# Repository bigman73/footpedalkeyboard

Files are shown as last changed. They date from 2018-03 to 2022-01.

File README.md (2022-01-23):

# Foot Pedal Keyboard
A foot pedal keyboard, using Korg EC5, Arduino and Python
Converts pedal button events into operating system virtual keyboard sequences.

## Sample applications

### Media editing 📸
Control media editing software, such as Adobe Photosop and Premiere, with your foot

### Program code 👨‍💻
Use the foot keyboard pedal to send macros to a code IDE, such as Visual Studio Code

### Practicing musical instruments 🎸
Control playback with your foot, without stopping the practice. The hands stay on the instrument (e.g, Bass guitar) and hitting a foot pedal rewinds the playback to the start.

### Using with Practice#
For example: If Pedal A is clicked (pressed and released) then the python driver will generate a Media Prev keyboard stroke on the operating system. A musician can then control music playback by using his/her feet, a very natural way for musicians that use foot pedals for effects and volume control, when playing instruments such as guitar, bass guitar and keyboards.

Originally, I wanted to be able to able to control [Practice#](https://github.com/bigman73/practicesharp), my open source practice application, with my feet - instead of getting out of practice position and having to use my hands in order control the application 
With Practice# the setup is as followes:
+ Pedal A -> Look back (key = l)
+ Pedal B -> Rewind a few seconds back (key = ,)
+ Pedal C -> Toggle Play / Pause (key = space)
+ Pedal D -> Slow down (key = s)
+ Pedal E -> Speed up (key = f)

But I decided to make a more generic solution. The python driver supoorts dynamic supports any desktop application through an easy to configure json file (key-mappings.json). The default configuration file contains Chrome mappings - a tab can be closed with Pedal E!  

### Video games
A foot keyboard can provide extra keys to use in games such as first person shooters (FPS).
For example: Pedal A could be assigned to a `crouch` action, or to a series of keyboard actions that would be executed in sequence

## Korg EC5 Foot Pedal Board
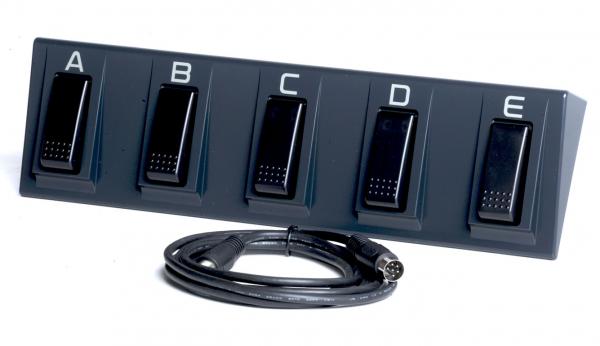
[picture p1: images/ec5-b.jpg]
Korg EC5 Foot Pedal Board


## The final result
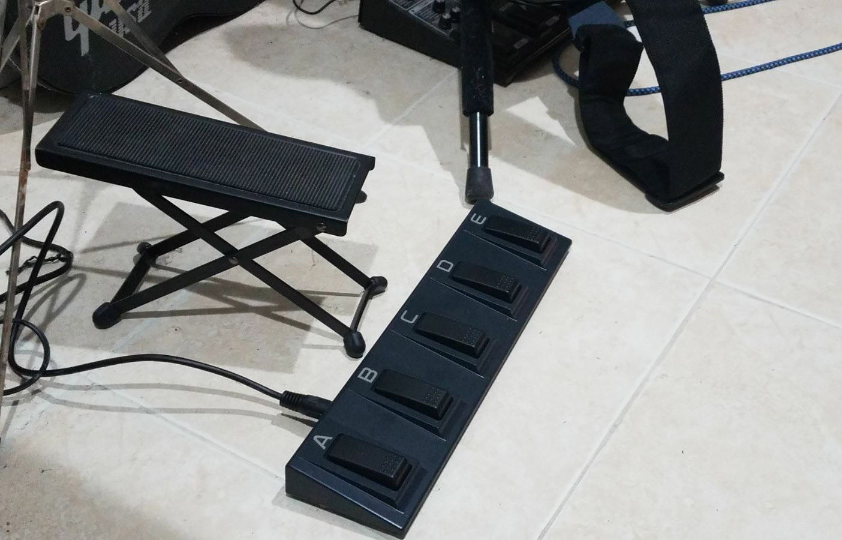
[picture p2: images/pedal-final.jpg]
Used in 'production' :)

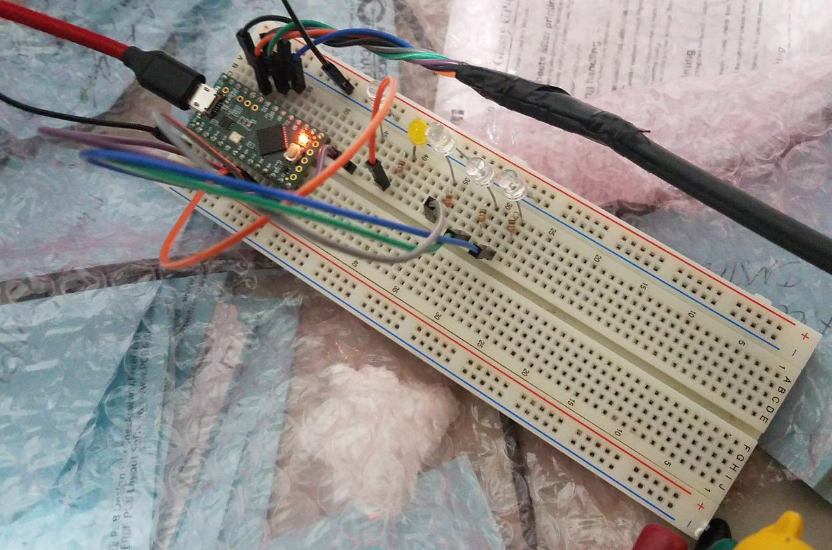
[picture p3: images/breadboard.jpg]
The breadboard solution

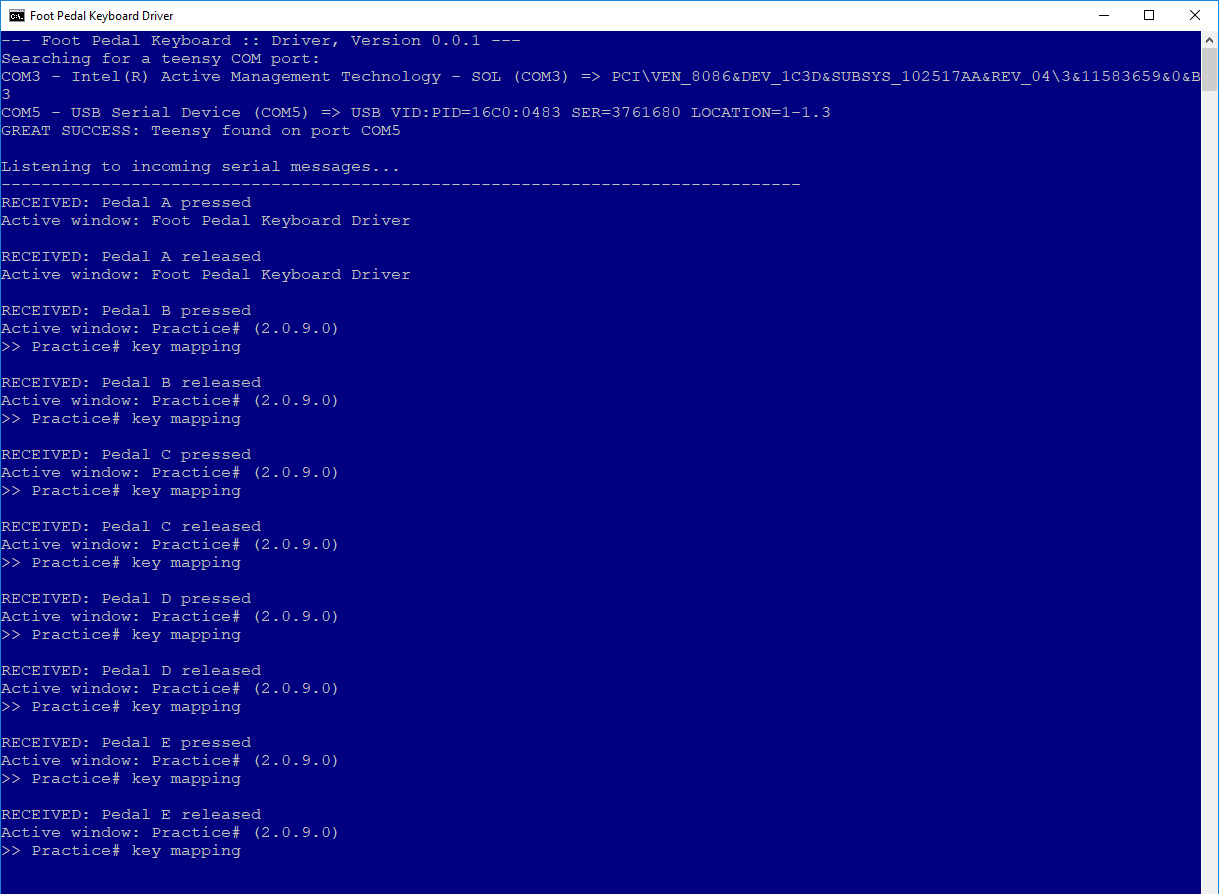
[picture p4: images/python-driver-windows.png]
The FPK python driver running on Windows


## More information - In the wiki
Bill Of Materials, wiring schematics and other details: 
https://github.com/bigman73/footpedalkeyboard/wiki

## Credits
I took some direction and ideas from a similar project done by Sylvain Wallez:
https://bluxte.net/musings/2016/07/29/usb-foot-keyboard/

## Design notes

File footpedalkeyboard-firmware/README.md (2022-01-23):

# Requirements
Prior to compiling and upload the firmware some preparation steps are needed

## 1. Install Arduino IDE
1. Download and install Arduino IDE
https://www.arduino.cc/en/Main/Software

>    As of January 2022-> version 1.8.19

## 2. Install Teensyduino
1. Download Teensyduino installer from
https://www.pjrc.com/teensy/td_download.html

> As of January 2022 -> version 1.56

2. Select the Arudino IDE folder (from step 1) as the target folder
3. Unselect all libraries (select None)
4. Install

## 3. Select Teensy LC Board
1. Main menu / Tools / Board "..." / Teensyduino
2. Select `Teensy LC`

## 4. Install bounce2 library
1. Main menu / Tools / Manage Libraries...
2. Select the library `bounce2`
>    As of January 2022 -> version 2.60.0

# Hardware Configuration
## Korg EC-5
[Korg EC-5 External Controller - Product page](https://www.korg.com/us/products/accessories/ec_5/)

### Top View

Korg EC-5, top
### Rear View
The modified MIDI cable connects to the port in the rear
Korg EC-5, rear

## Wiring Korg EC-5 Pins
| KORG CABLE WIRE | PEDAL | SOLDERED WIRE |
|---|:---:|---:|
| Yellow 🟨 |  [GND] | Black ⬛ |
| Black ⬛ |  A | Purple 🟪 |
| Red 🟥 |  B | Orange 🟧 |
| Grey 🗄  |  C | Gray 🗄 |
| Green 🟩 |  D | Green 🟩 |
| Blue 🟦 |  E | Blue 🟦 |

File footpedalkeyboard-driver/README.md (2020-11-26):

# Overview
A foot pedal keyboard, using Korg EC5, Arduino and Python Converts pedal button events (press, release) into operating system virtual keyboard sequences.

# Getting Started
## Installation steps

1. Install miniconda with Python 3.7+ 
https://conda.io/miniconda.html
> Version 3.7 as of November 2019

2. Create `conda` environment:
```
conda create --name py37_fpk python=3.7
```

3. Activate `conda` environment:
Linux: 
```
source activate py37_fpk
```

Windows: 
```
activate py37_fpk
```

4. Upgrade `pip`:
```
python -m pip install --upgrade pip
```

5. Install the modules `pyserial` and `pyautogui`:
```
pip install pyserial pyautogui
```

6. Install `win32gui` [windows only]
    1. Download whl: https://www.lfd.uci.edu/~gohlke/pythonlibs/#pywin32

  > For Windows 10 64 bit, Python 3.7 use => pywin32-227-cp37-cp37m-win_amd64.whl

  2. Install the `pywin32` whl: 
```
pip install pywin32-227-cp37-cp37m-win_amd64.whl
```
***

## How to run the Foot Pedal Keyboard driver on Windows

1. Change the folder to $(root)\footpedalkeyboard-driver
2. Open command shell (cmd.exe)
```
run.bat
```

> This can be automated with a Windows task that runs on desktop login

## Configure keyboard mapping
Pedal to Keyboard mapping is done using the **key-mappings.json** configuration file.

`pyautogui` module provides support for keyboard automation (programmatic keyboard actions).
The different values are documented in the [reference page](https://pyautogui.readthedocs.io/en/latest/keyboard.html#keyboard-keys)

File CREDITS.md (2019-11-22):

## USB Foot Keyboard
Sylvain Wallez

https://bluxte.net/musings/2016/07/29/usb-foot-keyboard

## Bounce2 (debouncer)
Debouncing library for Arduino and Wiring by Thomas Ouellet Fredericks with contributions from: Eric Lowry, Jim Schimpf, Tom Harkaway, Joachim Krüger and MrGradgrind.

https://github.com/thomasfredericks/Bounce2

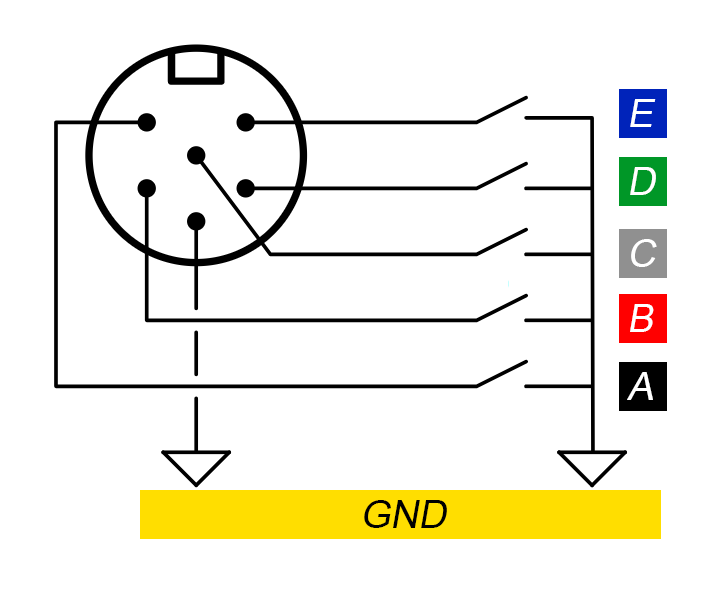
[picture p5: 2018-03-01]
images/Korg EC5 Cable Schematic.png

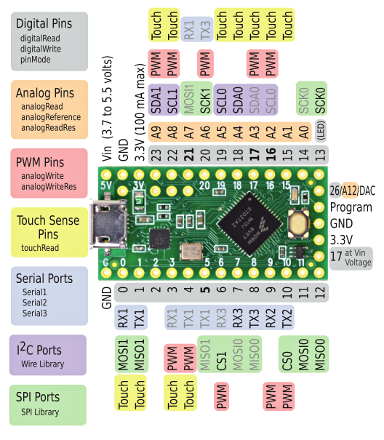
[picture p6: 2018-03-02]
images/teensylc_front_pinout.png

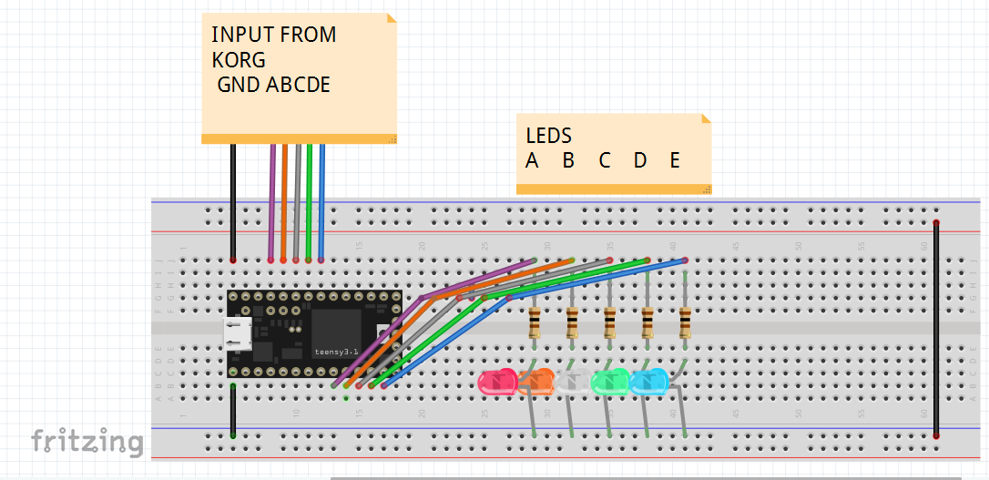
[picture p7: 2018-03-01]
fritzing/FritizingScreenshot.png

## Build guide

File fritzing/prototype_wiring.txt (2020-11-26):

Part/Wire                |Breadboard From                      |Breadboard To
============================================================================
Teensy LC                |GND (bottom left corner, near port 0)|H63
Teensy LC                |Pin 13                               |D50
GND Black Wire           |A62                                  |Top (-) Rail
Korg EC5 Gnd Wire (black)|B62 (above GND top left, right of Vin)
Korg EC5 A Wire (purple) |A61 (above port 23)
Korg EC5 B Wire (orange) |B60 (above port 22)
Korg EC5 C Wire (grey)   |A59 (above port 21)
Korg EC5 D Wire (green)  |B58 (above port 20)
Korg EC5 E Wire (blue)   |A57 (above port 19)
purple wire              |J54 (below port 8)                   |E46
ornage wire              |J53 (below port 9)                   |E42
grey wire                |J52 (below port 10)                  |E36
green wire               |J51 (below port 11)                  |E32
blue wire                |J50 (below port 12)                  |E29
LED A resistor 220 ohm   |A46                                  |C45
LED B resistor 150 ohm   |A42                                  |C41
LED C resistor 220 ohm   |A36                                  |C35
LED D resistor 150 ohm   |A32                                  |C31
LED E resistor 150 ohm   |A29                                  |C28
LED A purple             |A45                                  |Top (-) rail
LED B orange             |A41                                  |Top (-) rail
LED C white              |A35                                  |Top (-) rail
LED D green              |A31                                  |Top (-) rail
LED E blue               |A28                                  |Top (-) rail

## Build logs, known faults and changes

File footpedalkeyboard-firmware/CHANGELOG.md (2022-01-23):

# # Foot Pedal Keyboard Firmware - Change Log

## Versions

1.0.0, 2022-01-22
- chore: refactor and rename constants
- docs: improved inline code documentation
- docs: added firmware CHANGELOG.md
- docs: updated latest version of bounce2, arudino IDE and teensyduino

0.0.4, 2019-11-21
- feat: initial stable version

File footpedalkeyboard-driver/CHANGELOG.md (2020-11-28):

# Change Log

## Versions

1.2.0, 2020-11-28
- Code refactoring
- Code cleanup, with pylint
- Added mapping to VS Code
- Shortened driver python file to driver.py
- Updated conda dependencies

1.1.1, 2020-11-25
- Fixed typo
- Improved documentation

1.1.0, 2020-10-31
- Added support for process name based active application matching
- Fixed key mappings for Spotify to work on process name 
- Code refactor and cleanup

1.0.0, 2020-10-27
- Added key mappings support for Winamp

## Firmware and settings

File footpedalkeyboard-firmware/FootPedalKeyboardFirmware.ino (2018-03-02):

/* =============================================================================
MIT License

Copyright (c) 2018 Yuval Naveh (bigman73)

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
THE SOFTWARE IS PROVIDED "AS IS", WITHOUT WARRANTY OF ANY KIND, EXPRESS OR
IMPLIED, INCLUDING BUT NOT LIMITED TO THE WARRANTIES OF MERCHANTABILITY,
FITNESS FOR A PARTICULAR PURPOSE AND NONINFRINGEMENT. IN NO EVENT SHALL THE
AUTHORS OR COPYRIGHT HOLDERS BE LIABLE FOR ANY CLAIM, DAMAGES OR OTHER
LIABILITY, WHETHER IN AN ACTION OF CONTRACT, TORT OR OTHERWISE, ARISING FROM,
OUT OF OR IN CONNECTION WITH THE SOFTWARE OR THE USE OR OTHER DEALINGS IN THE
SOFTWARE.
=============================================================================== */

// Include the Bounce2 library found here :
// https://github.com/thomasfredericks/Bounce2
#include <Bounce2.h>

// Teensy 3.x / Teensy LC have the LED on pin 13
const int ledPin = 13;

const int ledPedalAPin = 8;
const int ledPedalBPin = 9;
const int ledPedalCPin = 10;
const int ledPedalDPin = 11;
const int ledPedalEPin = 12;

const int buttonPin = 17;

const int pedalAPin = 23; // Purple
const int pedalBPin = 22; // Orange
const int pedalCPin = 21; // Grey
const int pedalDPin = 20; // Green
const int pedalEPin = 19; // Blue

// Instantiate a Bounce object
Bounce debouncerPedalA = Bounce();
Bounce debouncerPedalB = Bounce();
Bounce debouncerPedalC = Bounce();
Bounce debouncerPedalD = Bounce();
Bounce debouncerPedalE = Bounce();

int ledState = 0;
int buttonState = 0;         // variable for reading the pushbutton status
int pedalState = 0;         // variable for reading the pedal wire status
unsigned long startTime;
unsigned long elapsedTime;


// the setup() method runs once, when the sketch starts

void setup() {
  Serial.begin(9600);  
  Serial.println("-- FootPedalKeyboard, Version: 0.01 ---");

  // initialize the digital pin as an output.
  pinMode(ledPin, OUTPUT);
  pinMode(ledPedalAPin, OUTPUT);
  pinMode(ledPedalBPin, OUTPUT);
  pinMode(ledPedalCPin, OUTPUT);
  pinMode(ledPedalDPin, OUTPUT);
  pinMode(ledPedalEPin, OUTPUT);

  pinMode(buttonPin, INPUT);
  pinMode(pedalAPin, INPUT_PULLUP);
  pinMode(pedalBPin, INPUT_PULLUP);
  pinMode(pedalCPin, INPUT_PULLUP);
  pinMode(pedalDPin, INPUT_PULLUP);
  pinMode(pedalEPin, INPUT_PULLUP);

  // After setting up the button, setup the Bounce instance:
  debouncerPedalA.attach(pedalAPin);
  debouncerPedalA.interval(5); // interval in ms
  debouncerPedalB.attach(pedalBPin);
  debouncerPedalB.interval(5); // interval in ms
  debouncerPedalC.attach(pedalCPin);
  debouncerPedalC.interval(5); // interval in ms
  debouncerPedalD.attach(pedalDPin);
  debouncerPedalD.interval(5); // interval in ms
  debouncerPedalE.attach(pedalEPin);
  debouncerPedalE.interval(5); // interval in ms

  digitalWrite(ledPedalAPin, LOW);
  digitalWrite(ledPedalBPin, LOW);
  digitalWrite(ledPedalCPin, LOW);
  digitalWrite(ledPedalDPin, LOW);
  digitalWrite(ledPedalEPin, LOW);
  
  startTime = millis();
}

// the loop() methor runs over and over again,
// as long as the board has power

void loop() {
  // Update the Bounce instances
  debouncerPedalA.update();
  debouncerPedalB.update();
  debouncerPedalC.update();
  debouncerPedalD.update();
  debouncerPedalE.update();
  
  elapsedTime = millis() - startTime;

  if (elapsedTime > 400) {
    ledState = 1 - ledState;
    if (ledState) {
      digitalWrite(ledPin, HIGH);   // set the LED on    
    } else {
      digitalWrite(ledPin, LOW);    // set the LED off
    }
    startTime = millis();
  }

  handleButtonChange(debouncerPedalA, ledPedalAPin, "A");
  handleButtonChange(debouncerPedalB, ledPedalBPin, "B");
  handleButtonChange(debouncerPedalC, ledPedalCPin, "C");
  handleButtonChange(debouncerPedalD, ledPedalDPin, "D");
  handleButtonChange(debouncerPedalE, ledPedalEPin, "E");
  
  delay(25);
}

void handleButtonChange(Bounce debouncerPedal, int ledPedalPin, String pedalName) {
   if ( debouncerPedal.fell() ) {
     Serial.println("Pedal " + pedalName + " pressed");
     digitalWrite(ledPedalPin, HIGH);
   } else if ( debouncerPedal.rose() ) {
     Serial.println("Pedal " + pedalName + " released");
     digitalWrite(ledPedalPin, LOW);
   }  
}

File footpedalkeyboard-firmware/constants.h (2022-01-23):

const String FIRMWARE_VERSION = "1.0.0";

// Teensy 3.x / Teensy LC have the LED on pin 13
const int MAIN_LED_PEN = 13;
const int STATUS_LED_BLINK_TIME = 400; // msec
const int SERIAL_DATA_RATE = 9600; // baud
const int STARTUP_TEST_DELAY = 150; // msec

const int LED_PEDAL_PIN_A = 8;
const int LED_PEDAL_PIN_B = 9;
const int LED_PEDAL_PIN_C = 10;
const int LED_PEDAL_PIN_D = 11;
const int LED_PEDAL_PIN_E = 12;

const int NUM_PEDALS = 5;
const int ledPedalPins[] = {LED_PEDAL_PIN_A, LED_PEDAL_PIN_B, LED_PEDAL_PIN_C, LED_PEDAL_PIN_D, LED_PEDAL_PIN_E};

// See README.md of firmware for Korg EC-5 cable pins mapping
const int INPUT_PEDAL_PIN_A = 23; // Purple
const int INPUT_PEDAL_PIN_B = 22; // Orange
const int INPUT_PEDAL_PIN_C = 21; // Grey
const int INPUT_PEDAL_PIN_D = 20; // Green
const int INPUT_PEDAL_PIN_E = 19; // Blue

const int inputPedalPins[] = {INPUT_PEDAL_PIN_A, INPUT_PEDAL_PIN_B, INPUT_PEDAL_PIN_C, INPUT_PEDAL_PIN_D, INPUT_PEDAL_PIN_E};

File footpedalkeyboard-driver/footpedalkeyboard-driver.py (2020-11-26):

""" =============================================================================
MIT License

Copyright (c) 2018 Yuval Naveh (bigman73)

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
THE SOFTWARE IS PROVIDED "AS IS", WITHOUT WARRANTY OF ANY KIND, EXPRESS OR
IMPLIED, INCLUDING BUT NOT LIMITED TO THE WARRANTIES OF MERCHANTABILITY,
FITNESS FOR A PARTICULAR PURPOSE AND NONINFRINGEMENT. IN NO EVENT SHALL THE
AUTHORS OR COPYRIGHT HOLDERS BE LIABLE FOR ANY CLAIM, DAMAGES OR OTHER
LIABILITY, WHETHER IN AN ACTION OF CONTRACT, TORT OR OTHERWISE, ARISING FROM,
OUT OF OR IN CONNECTION WITH THE SOFTWARE OR THE USE OR OTHER DEALINGS IN THE
SOFTWARE.
=============================================================================== """

import sys
import serial
from serial.tools import list_ports
from pyautogui import press, keyDown, keyUp, typewrite
import re
from window_services import get_active_window
import json
import psutil
import win32process
import win32gui
import time

DRIVER_VERSION = "1.1.1"

# Teensy USB serial microcontroller program id data:
VENDOR_ID = "16C0"
PRODUCT_ID = "0483"
TEENSY_SIGNATURE = "USB VID:PID={0}:{1}".format(VENDOR_ID, PRODUCT_ID)

MAX_CACHE_SIZE = 50

event_regex = re.compile('Pedal\\s([A-E])\\s(pressed|released)')

# Key: Mapping application name, Value: application mapping data
applications = {}

# Key: Window title, Value: Mapping application name
title_application_mapping_cache = {}

# Key: Process Name, Value: Mapping application name
process_application_mapping_cache = {}


def get_active_window_process_name():
    """
    Gets the process name for the currently active window
    """

    # This produces a list of PIDs active window relates to
    pid = win32process.GetWindowThreadProcessId(win32gui.GetForegroundWindow())
    # pid[-1] is the most likely to survive last longer
    process_name = psutil.Process(pid[-1]).name()

    return process_name


def find_teensy_port():
    """
    Finds the teensy COM port
    """

    print('Searching for a teensy COM port:')
    for port in list(list_ports.comports()):
        print(port, "=>", port[2])
        if port[2].startswith(TEENSY_SIGNATURE):
            return port[0]

    return None


def listen_to_teensy_serial(teensy_port):
    """
    Listens to teensy serial messages
    """

    ser = serial.Serial(port=teensy_port, baudrate=9600, timeout=0.1)
    print('Listening to incoming serial messages...')
    print('-' * 80)

    while True:
        arduino_messsage = ser.readline()
        if arduino_messsage and len(arduino_messsage) > 0:
            event = arduino_messsage.decode("utf-8")
            event = event.replace('\r\n', '')
            process_footpedalkeyboard_event(event)
            print()


def process_footpedalkeyboard_event(event):
    """
    Processes an event coming from the foot pedal keyboard
    """

    print("RECEIVED KEYBOARD EVENT: " + event)

    matchingEvent = event_regex.match(event)
    if matchingEvent:
        pedal = matchingEvent.group(1)
        pedal_action = matchingEvent.group(2)

        active_window_title = get_active_window()
        print("Active window:", active_window_title)

        active_window_process_name = get_active_window_process_name()
        print("Active process:", active_window_process_name)

        matching_application = None

        cached_application_name = title_application_mapping_cache.get(
            active_window_title)

        # Lookup cache by active window title
        if cached_application_name:
            print("Using a cached application (by window title) =>",
                  cached_application_name)
            matching_application = applications[cached_application_name]

        # Lookup cache by process name of active window
        if not matching_application:
            cached_application_name = process_application_mapping_cache.get(
                active_window_process_name)
            if cached_application_name:
                print("Using a cached application (by process name) =>",
                      cached_application_name)
                matching_application = applications[cached_application_name]

        # Match application by active window's title
        if not matching_application:
            for application_name, application in applications.items():
                if not 'window_title_compiled_regex' in application:
                    continue

                window_title_compiled_regex = application['window_title_compiled_regex']
                if window_title_compiled_regex.match(active_window_title):
                    print("Found a matching application by window title =>",
                          application_name)
                    matching_application = application
                    # Add to cache for next time
                    if title_application_mapping_cache.__len__() > MAX_CACHE_SIZE:
                        title_application_mapping_cache.clear()
                    title_application_mapping_cache[active_window_title] = application['application_name']
                    break

        # Match application by active window's process name
        if not matching_application:
            for application_name, application in applications.items():
                if not 'process_name_compiled_regex' in application:
                    continue

                process_name_compiled_regex = application['process_name_compiled_regex']
                if process_name_compiled_regex.match(active_window_process_name):
                    print("Found a matching application by process name =>",
                          application_name)
                    matching_application = application
                    # Add to cache for next time
                    if process_application_mapping_cache.__len__() > MAX_CACHE_SIZE:
                        process_application_mapping_cache.clear()
                    process_application_mapping_cache[active_window_process_name] = application['application_name']
                    break

        if matching_application:
            apply_application_keys(matching_application, pedal, pedal_action)
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

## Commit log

2018-03-01 Initial Fritizing
    [FootPedalKeyboard Fritzing Sketch.fzz]
2018-03-01 Korg EC5 Cable Schematic
2018-03-01 Added Korg EC5 cable wiring
2018-03-01 Wire mapping
2018-03-01 Cable wiring mappings
2018-03-02 Initial and functional version of the python driver
2018-03-02 Changes led pins to use lower row
2018-03-02 teensylc front pinout
2018-03-02 screenshot of the python driver running on Windows
2018-03-03 Refactoring Added start routine (flash all LEDs to ensure they work)
2018-03-03 refactor handling of status led
2018-03-10 Added support for typewrite action - the ability to have the driver inject keyboard sequence with an interval as if the user type wrote it with a real keyboard
2018-03-10 Add mappings to Notepad, for demonstration of type write action as testing the Pressed button event type
2018-05-05 prototype wiring - before the prototype becomes soldered
2018-08-19 Fixed typo in filename, correct to footpedalkeyboard-driver (instead of food..)
    [footpedalkeyboard-driver.py]
2019-11-24 gitignore for fpk python driver
2019-11-24 Added FPK driver configuration section
2020-10-31 - Added support for process name based active application matching - Fixed key mappings for Spotify to work on process name - Code refactor and cleanup
    [footpedalkeyboard-driver.py]
2020-11-26 fixed documentation of wiring
2020-11-26 fixed port numbers for korg wires
2020-11-26 fixed wiring grid layout
2020-11-28 - Code refactoring - Code cleanup, with pylint - Added mapping to VS Code - Shortened driver python file to driver.py
    [driver.py]
2022-01-23 docs: updated versions of arduino IDE and teensyduino
2022-01-23 docs: updated latest version of bounce2, arudino IDE and teensyduino
